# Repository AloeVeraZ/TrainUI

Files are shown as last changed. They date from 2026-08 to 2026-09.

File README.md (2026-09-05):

<div align="center">

# Train UI

### A live NYC train display I built in two sizes




</div>

---

## Overview

I built Train UI so I could see the next trains without opening an app. Pick a train and station once, then leave the display running.

## How it works

Both versions connect directly to the MTA's public realtime feeds. Your train and station stay saved on the device, which refreshes arrivals, service status, weather, time, and connection information without a phone app, account, or API key.

## Choose a version

| Train UI XL | Train UI Mini |
| --- | --- |
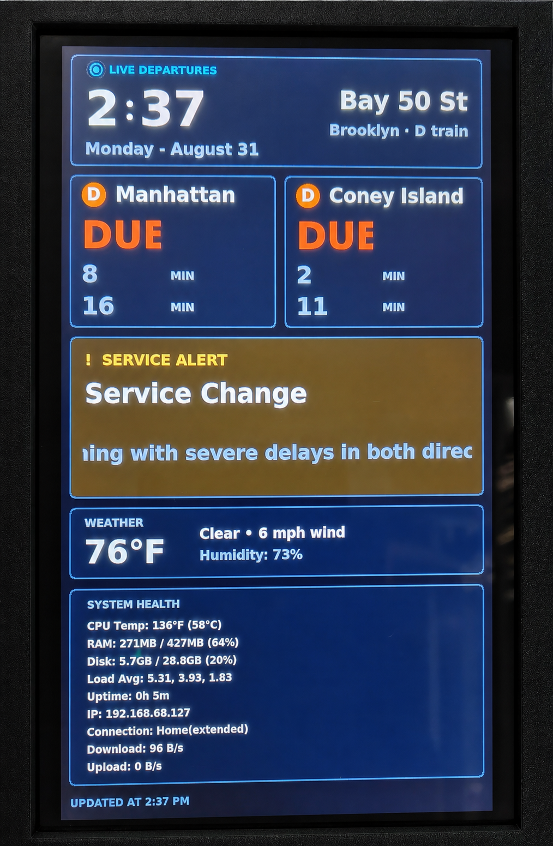
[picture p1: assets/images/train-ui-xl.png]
Train UI XL showing live departures
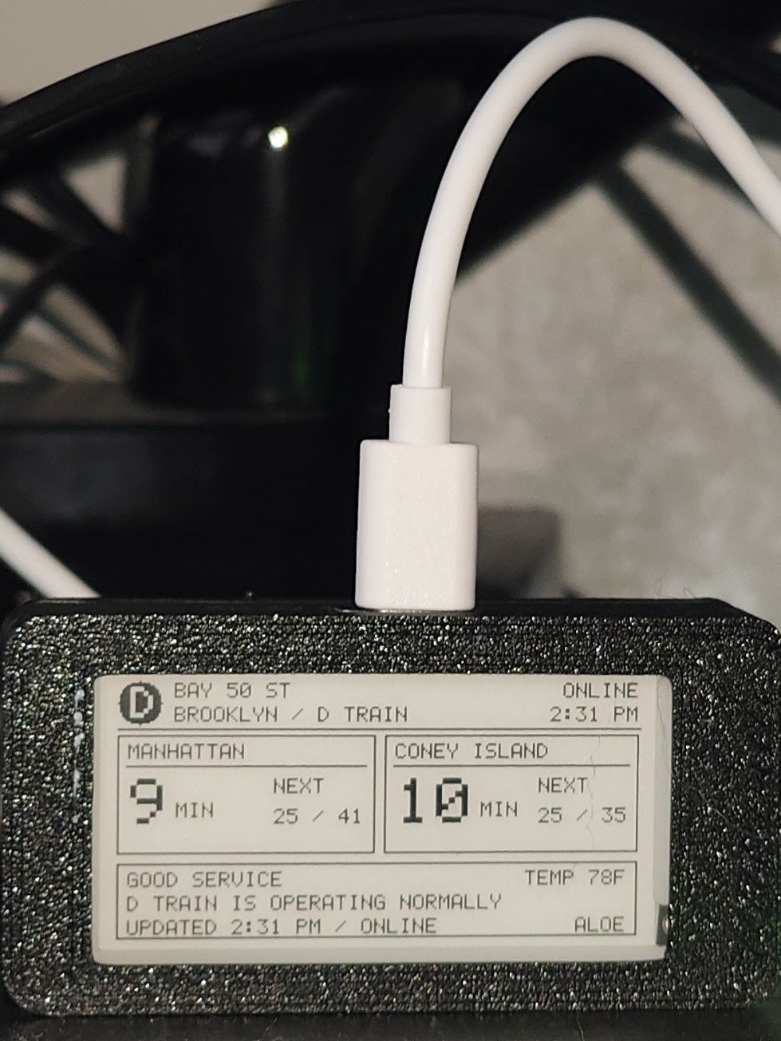
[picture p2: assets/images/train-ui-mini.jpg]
Train UI Mini e-paper display
|  |  |
| Raspberry Pi Zero W and a 10.1-inch color screen | ESP32-S3 and a 2.13-inch e-paper screen |
| Full dashboard, weather, and Pi health | Smaller, cheaper, and simpler |
| [Build the XL](Train%20UI%20XL/) | [Build the Mini](Train%20UI%20Mini/) |

## XL CAD files

| File | Use |
| --- | --- |
| [case for screen.step](Train%20UI%20XL/CAD/case%20for%20screen.step) | Full STEP assembly for reference and editing |
| [Only 3DP files.step](Train%20UI%20XL/CAD/Only%203DP%20files.step) | **Only the parts that need to be 3D printed** |
| [case for screen.f3z](Train%20UI%20XL/CAD/case%20for%20screen.f3z) | Editable Fusion 360 archive |

Use **Only 3DP files.step** when you only want the printable enclosure pieces. It leaves out the reference electronics and hardware from the full assembly.

## What they show

- Arrivals in both directions
- MTA service status and alerts
- Weather, time, and connection status
- Live public data with no API key

For a bar or other across-the-room installation, use the separate
[Train UI XL Trackside edition](Train%20UI%20XL/Train%20UI%20XL%20Trackside/).

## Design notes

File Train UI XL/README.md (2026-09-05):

<div align="center">

# Train UI XL

### My full-size NYC train display





<a href="#overview">Train UI XL showing live departures</a>

[Parts](#parts) • [CAD](#cad-files) • [Assembly](Assembly%20Guide/) • [Install](#install) • [Commands](#commands)

</div>

---

## Overview

I built Train UI XL around a Raspberry Pi Zero W and a 10.1-inch screen. It shows arrivals, service alerts, weather, time, and Pi health, then starts itself whenever the Pi boots.

### Trackside edition

[Train UI XL Trackside](Train%20UI%20XL%20Trackside/) is the separate bar-commissioned
layout. It keeps the same hardware and installer, but uses an extra-large clock,
large departure times, a five-day forecast, and a compact system-health footer.

> [!WARNING]
> This build needs soldering. Keep power disconnected. Feed the cut Micro-USB cable through the printed back **before soldering**, verify polarity with a multimeter, solder red to `V` and black to `G`, insulate every unused wire, and check for a `V`–`G` short before power-up.

## Parts

This is the bill of materials for the XL build.

| Qty. | Core part |
| ---: | --- |
| 1 | Original Raspberry Pi Zero W |
| 1 | 10.1-inch 1024 × 600 HDMI display |
| 1 | MicroSD card |
| 1 | Stable 5V power supply |

### Cables and hardware

<table>
  <tr>
    <td width="33%" valign="top" align="center">
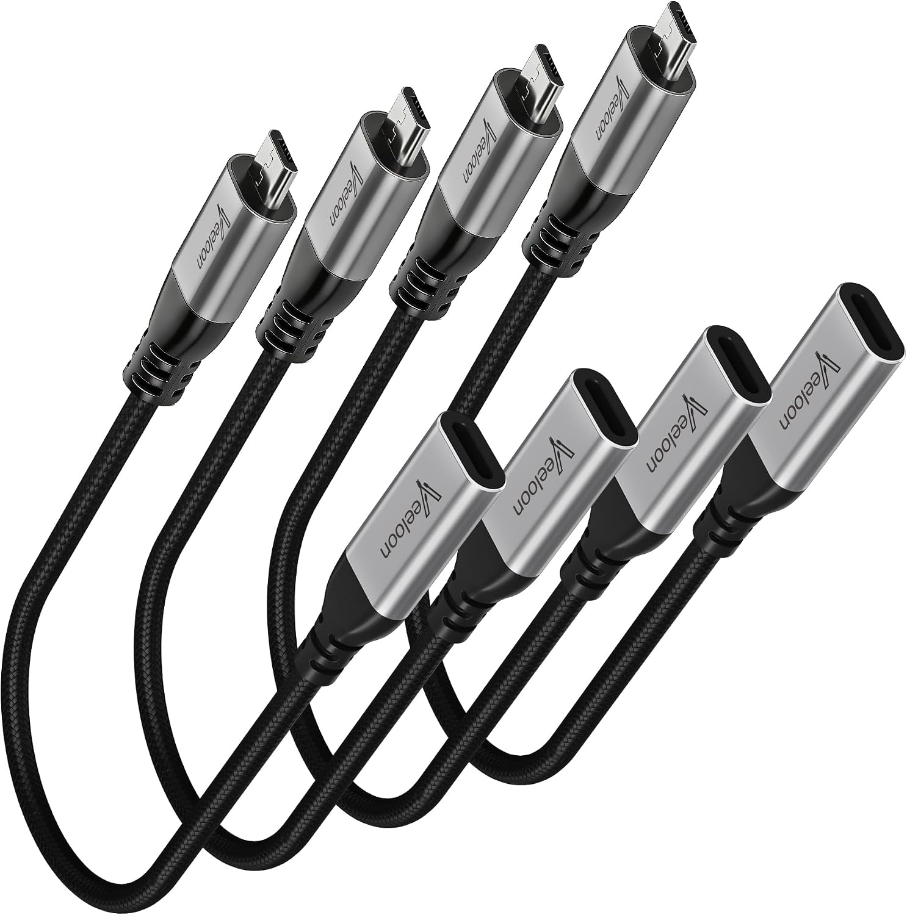
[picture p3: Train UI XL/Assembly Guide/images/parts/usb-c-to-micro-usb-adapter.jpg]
USB-C female to Micro-USB male adapter cable
      <br>
      <strong><a href="https://www.amazon.com/dp/B0G5YZJLVZ">USB-C to Micro-USB adapter lead</a></strong><br>
      Becomes the internal Pi power lead.
    </td>
    <td width="33%" valign="top" align="center">
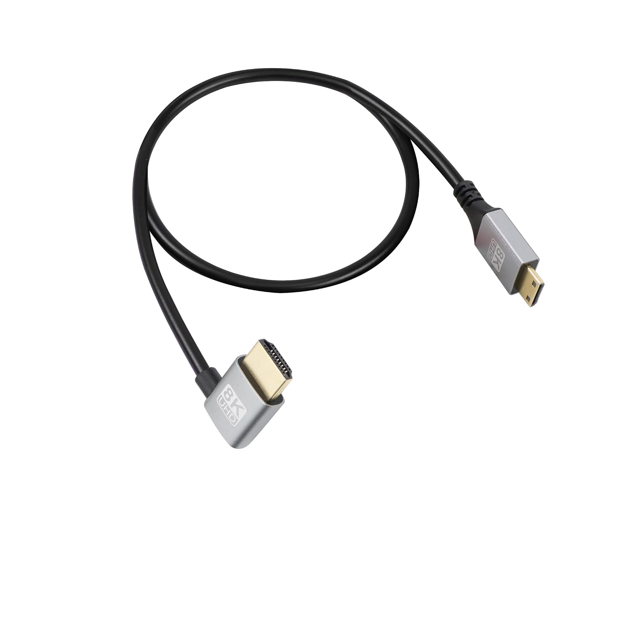
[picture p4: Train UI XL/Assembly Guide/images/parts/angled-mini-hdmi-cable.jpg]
Angled HDMI to mini-HDMI cable
      <br>
      <strong><a href="https://www.amazon.com/dp/B0CNGV7FQJ">90-degree HDMI to mini-HDMI cable</a></strong><br>
      Connects the Pi to the screen.
    </td>
    <td width="33%" valign="top" align="center">
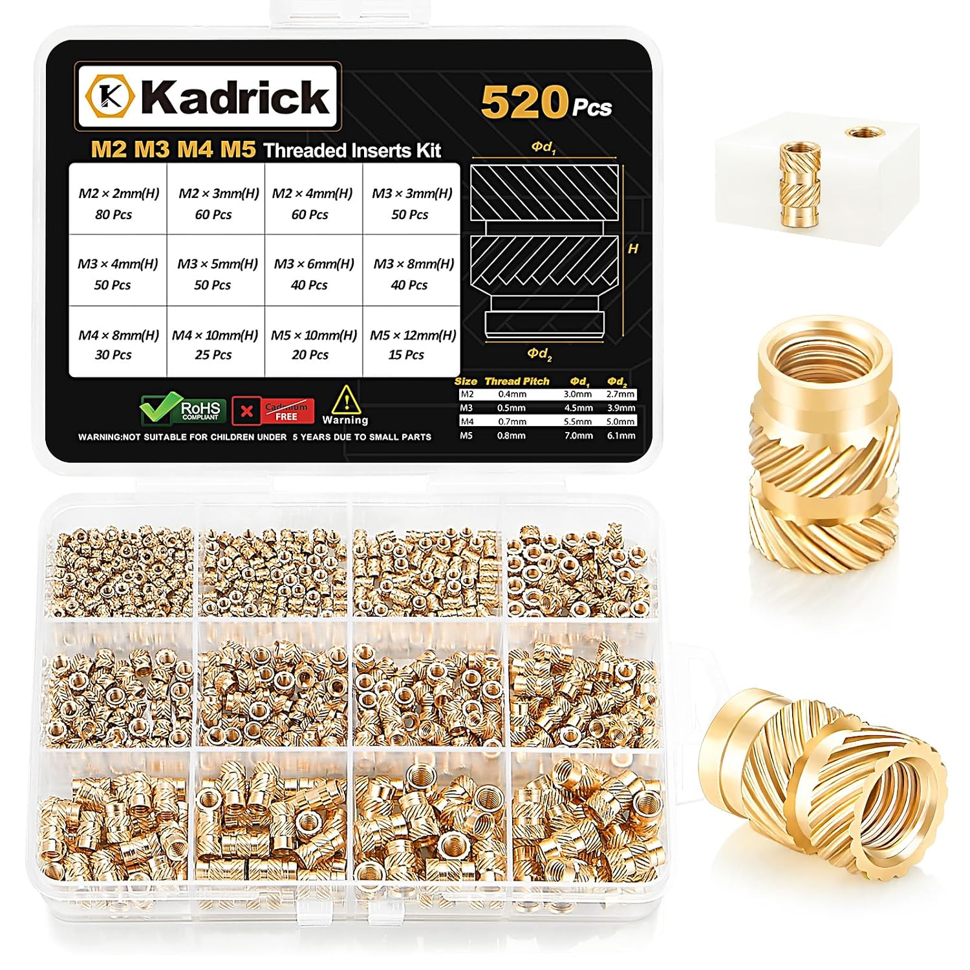
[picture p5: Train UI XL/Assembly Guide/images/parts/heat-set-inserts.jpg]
M2 through M5 heat-set insert kit
      <br>
      <strong><a href="https://www.amazon.com/dp/B0D5V3TZLB">M2–M5 heat-set inserts</a></strong><br>
      Adds metal threads to the printed parts.
    </td>
  </tr>
  <tr>
    <td width="33%" valign="top" align="center">
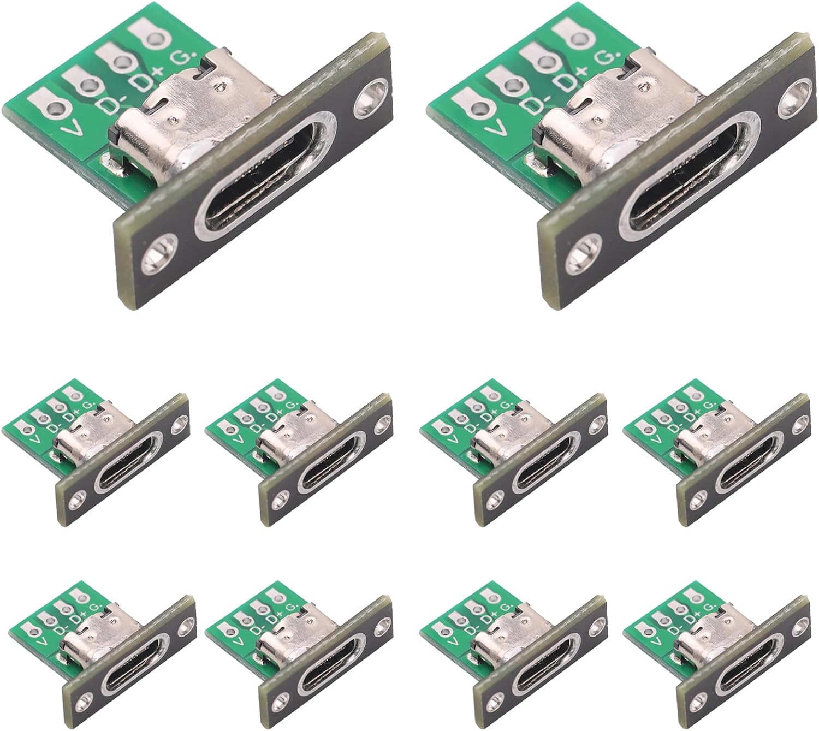
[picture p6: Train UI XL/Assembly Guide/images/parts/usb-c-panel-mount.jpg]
USB-C female panel-mount socket boards
      <br>
      <strong><a href="https://www.amazon.com/dp/B0F3WVBGCP">USB-C panel-mount socket</a></strong><br>
      Becomes the outside power inlet.
    </td>
    <td width="33%" valign="top" align="center">
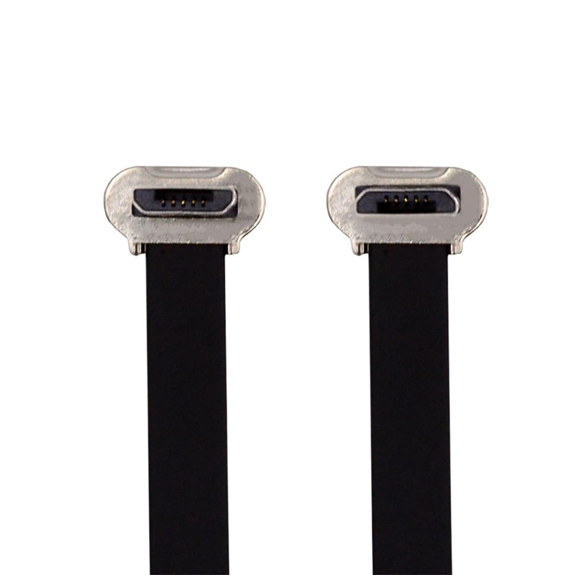
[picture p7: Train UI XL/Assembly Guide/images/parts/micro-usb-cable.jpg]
Short 90-degree Micro-USB male-to-male cable
      <br>
      <strong><a href="https://www.amazon.com/dp/B0F87W7P59">Short 90-degree Micro-USB cable</a></strong><br>
      Keeps the internal power run compact.
    </td>
    <td width="33%" valign="top" align="center">
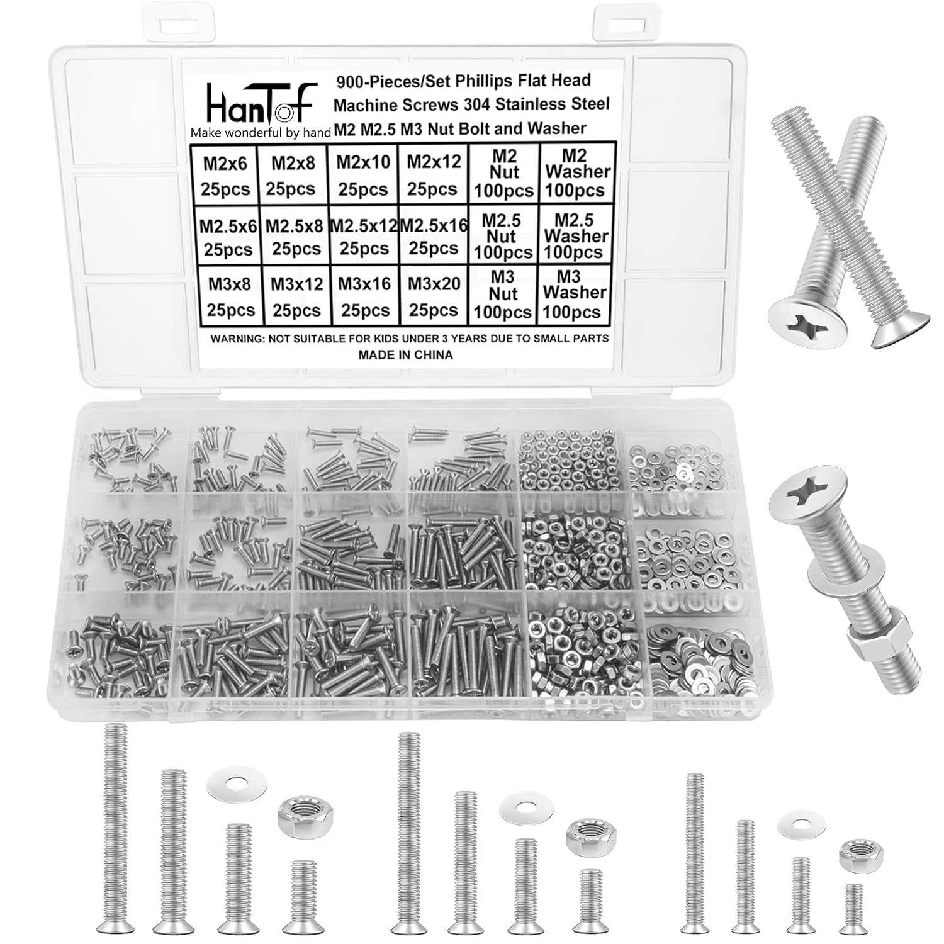
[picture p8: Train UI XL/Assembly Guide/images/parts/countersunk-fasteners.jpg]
Countersunk M2, M2.5, and M3 fastener assortment
      <br>
      <strong><a href="https://www.amazon.com/dp/B0FF4TDYKZ">Countersunk fasteners</a></strong><br>
      Holds low-profile parts flush.
    </td>
  </tr>
  <tr>
    <td colspan="3" align="center">
      <table width="67%">
        <tr>
          <td width="50%" valign="top" align="center">
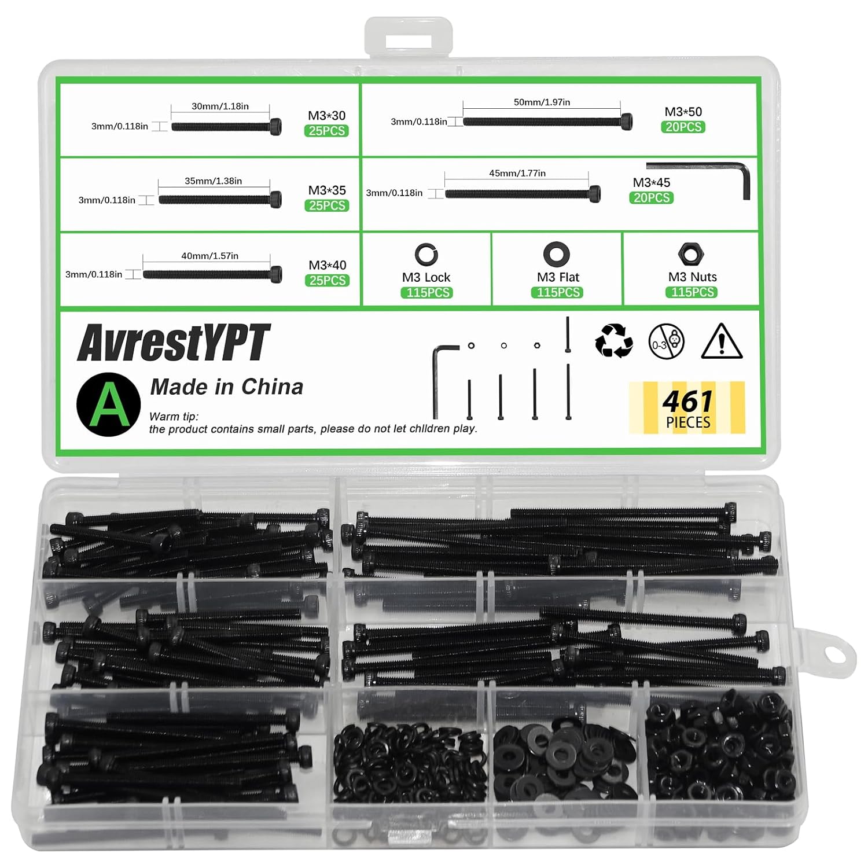
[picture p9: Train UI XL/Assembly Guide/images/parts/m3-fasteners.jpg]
M3 socket-head screw, nut, and washer assortment
            <br>
            <strong><a href="https://www.amazon.com/dp/B0FGJ9FRGQ">M3 socket-head fasteners</a></strong><br>
            Use four M3 × 25 mm screws to close the case.
          </td>
          <td width="50%" valign="top" align="center">
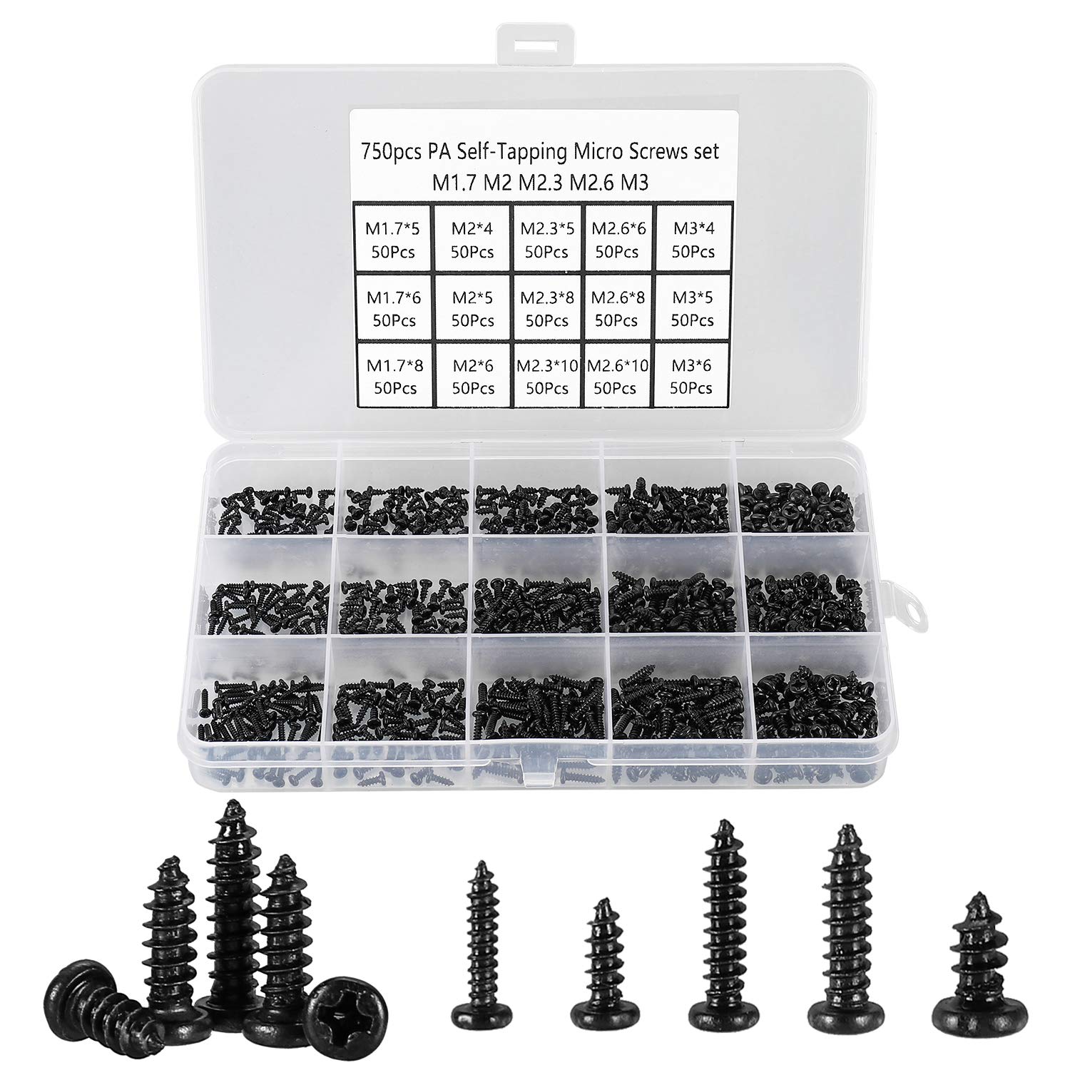
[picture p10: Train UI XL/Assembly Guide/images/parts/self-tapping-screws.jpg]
Small black self-tapping screw assortment
            <br>
            <strong><a href="https://www.amazon.com/dp/B07ZH9GJWP">Small self-tapping screws</a></strong><br>
            Secures light internal parts.
          </td>
        </tr>
      </table>
    </td>
  </tr>
</table>

**Tools:** soldering iron, wire cutters, wire strippers, multimeter, heat-shrink, heat-set tip, and matching hand tools.

## CAD files

| File | Use |
| --- | --- |
| [case for screen.step](CAD/case%20for%20screen.step) | Complete STEP assembly |
| [Only 3DP files.step](CAD/Only%203DP%20files.step) | **3D-printed parts only** |
| [case for screen.f3z](CAD/case%20for%20screen.f3z) | Editable Fusion 360 archive |

If you only want to slice or print the enclosure, download **Only 3DP files.step**. The full STEP and Fusion archive also include reference assembly content.

## Assembly

The [step-by-step assembly guide](Assembly%20Guide/) covers the faceplate, screen, Pi, power inlet, wiring, and final enclosure.

## Install

1. Use [Raspberry Pi Imager](https://www.raspberrypi.com/software/) to install Raspberry Pi OS 32-bit with Desktop.
2. Add 2.4 GHz Wi-Fi, enable SSH, and create your user.
3. Connect the screen, SSH into the Pi, and run:

```bash
curl -fsSL https://raw.githubusercontent.com/AloeVeraZ/TrainUI/main/Train%20UI%20XL/installer/install.sh | bash
```

Choose a train and station, then answer `Y` or `N` for daily display sleep. Enter exactly four digits in 24-hour `HHMM` format: `2300` is 11:00 PM, `0800` is 8:00 AM, and `2400` is midnight. The installer then sets automatic startup and Wi-Fi recovery and reboots.

If the Pi stays offline for 30 seconds, join **TrainUI** with password **TRAINUI1** and open `http://10.42.0.1`. The screen shows these setup details only while the hotspot is active.

## Update, change stations, or change sleep time

Run the same command again. Normal reruns use the fast update path: they download only the small XL runtime files, skip unchanged system setup, and do not reboot. You can change both the train/station and daily sleep times during the update:

```bash
curl -fsSL https://raw.githubusercontent.com/AloeVeraZ/TrainUI/main/Train%20UI%20XL/installer/install.sh | bash
```

## Commands

```bash
# Update TrainUI, change the station, and review the sleep schedule
curl -fsSL https://raw.githubusercontent.com/AloeVeraZ/TrainUI/main/Train%20UI%20XL/installer/install.sh | bash

# Change only the daily display sleep schedule
trainui-schedule

# View the log
tail -f "$HOME/TrainUI/Train UI XL/trainui.log"

# Check Wi-Fi setup
systemctl status trainui-wifi-setup.service
sudo journalctl -u trainui-wifi-setup.service --since today

```

Scheduled sleep powers down only the display. The desktop stays logged in and TrainUI keeps running, so wake time returns directly to the dashboard instead of a login screen.

## Quick fixes

| Problem | Check |
| --- | --- |
| SSH fails | Try the Pi's IP address and confirm SSH is enabled. |
| Screen stays blank | Let Raspberry Pi OS reach the desktop, then check the log. |
| Wi-Fi fails | Use 2.4 GHz, or join the setup hotspot after 30 seconds. |
| Rotation is wrong | Mount the screen at 270 degrees and rerun the installer. |

## Development

```bash
python3 -m unittest discover -s tests -v
python3 tests/validate_live_feeds.py
python3 timertest.py --smoke-test
```

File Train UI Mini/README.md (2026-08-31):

<div align="center">

# Train UI Mini

### My small e-paper NYC train display





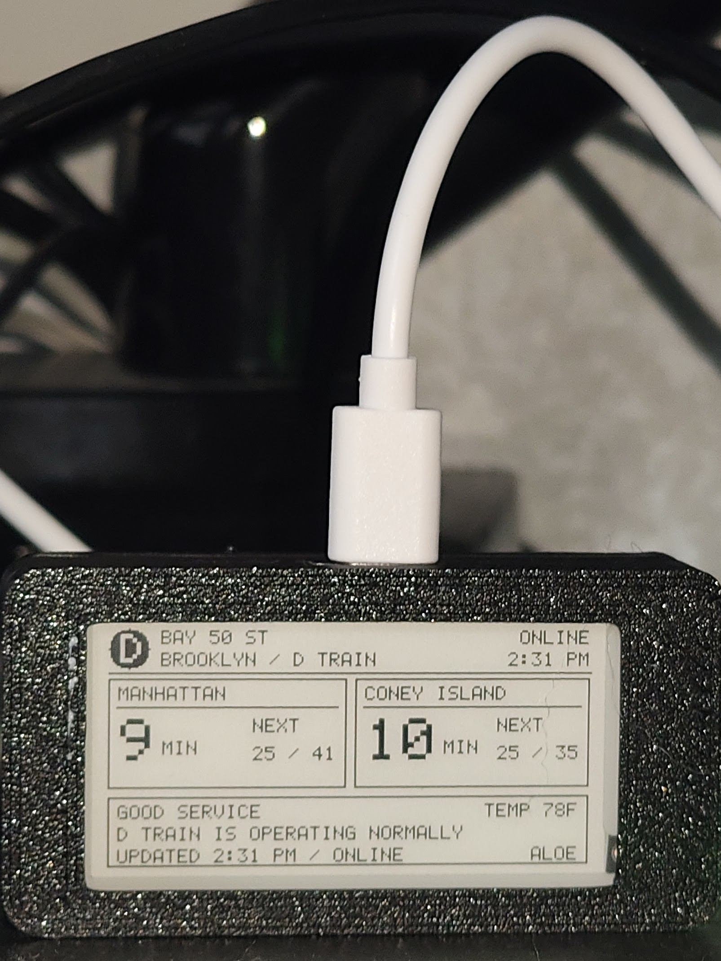
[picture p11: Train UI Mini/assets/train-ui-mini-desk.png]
Train UI Mini e-paper display


</div>

---

## Overview

I built Train UI Mini as a cheaper version of [Train UI XL](../Train%20UI%20XL/). It shows arrivals, service status, temperature, time, and connection status on one ESP32-S3 e-paper board.

## Parts

| Qty. | Part |
| --- | --- |
| 1 | [Elecrow CrowPanel ESP32-S3 2.13-inch e-paper display](https://www.amazon.com/dp/B0H25DMJ8M) |
| 1 | USB-C data cable |
| Optional | [3D-printed desk case](https://www.printables.com/model/1566902-case-for-crowpanel-213-epaper/related) |

## Setup

1. Install **esp32 by Espressif Systems** in Arduino IDE.
2. Open `TrainUIMiniCode/TrainUIMiniCode.ino`.
3. Use these settings and upload:

| Setting | Value |
| --- | --- |
| Board | ESP32S3 Dev Module |
| Flash Size | 8MB (64Mb) |
| PSRAM | OPI PSRAM |
| USB CDC On Boot | Enabled |

On first boot, join **TrainUIMini** with password **TRAINUI1**. Open `http://192.168.4.1`, enter your Wi-Fi, and choose a train and station.

## Controls

| Control | Action |
| --- | --- |
| Menu | Open setup again |
| Dial press | Switch between live and sample data |
| Back | Refresh |

The board uses public MTA and Open-Meteo data. No app, account, server, or API key is needed.

Train UI Mini is available under the [MIT License](LICENSE).

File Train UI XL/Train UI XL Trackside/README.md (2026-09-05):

# Train UI XL Trackside

Train UI XL Trackside is a dedicated, easy-to-read version commissioned for a
bar. It keeps the same Raspberry Pi Zero W hardware, MTA live departures,
Wi-Fi recovery, scheduled display power, automatic startup, and installation
flow as [Train UI XL](../README.md). It lives in its own folder so the
Trackside layout can be maintained separately from the main display.

## What is different

- The clock and date are enlarged for viewing across a room, with responsive
  sizing so the full weekday and month remain readable.
- Departure numbers and their `MIN` labels are enlarged to the largest size
  that fits each portrait card without clipping.
- The service-change panel is replaced by a five-day weather forecast.
- System health is compact and stays at the bottom with only CPU temperature,
  uptime, IP address, and Wi-Fi connection.

The Trackside installer uses separate application, configuration, log, Wi-Fi,
schedule, and systemd names so it does not overwrite a regular Train UI XL
installation. Its setup hotspot is **TrainUI Trackside** with password
**TRAINUI1** at `http://10.42.0.1`.

## Install

Use Raspberry Pi OS 32-bit with Desktop, enable SSH, add the 2.4 GHz network in
Raspberry Pi Imager, and run this as the normal Pi user:

```bash
curl -fsSL https://raw.githubusercontent.com/AloeVeraZ/TrainUI/main/Train%20UI%20XL/Train%20UI%20XL%20Trackside/installer/install.sh | bash
```

Choose the train and station, then answer `Y` or `N` for daily display sleep.
Enter times as exactly four digits in 24-hour `HHMM` format: `2300` is 11:00
PM, `0800` is 8:00 AM, and `2400` is midnight.

## Commands

```bash
# Update Trackside, change the station, or review the sleep schedule
curl -fsSL https://raw.githubusercontent.com/AloeVeraZ/TrainUI/main/Train%20UI%20XL/Train%20UI%20XL%20Trackside/installer/install.sh | bash

# Change only the Trackside display schedule
trainui-trackside-schedule

# View the Trackside log
tail -f "$HOME/TrainUI-Trackside/Train UI XL/Train UI XL Trackside/trainui-trackside.log"
```

Scheduled sleep powers down only the display. The logged-in desktop and
Trackside app remain active, so wake time returns directly to the dashboard.

## Hardware and assembly

Use the shared [parts and CAD files](../README.md) and the
[step-by-step assembly guide](../Assembly%20Guide/). The enclosure, screen,
Raspberry Pi Zero W orientation, power wiring, and fasteners are unchanged.

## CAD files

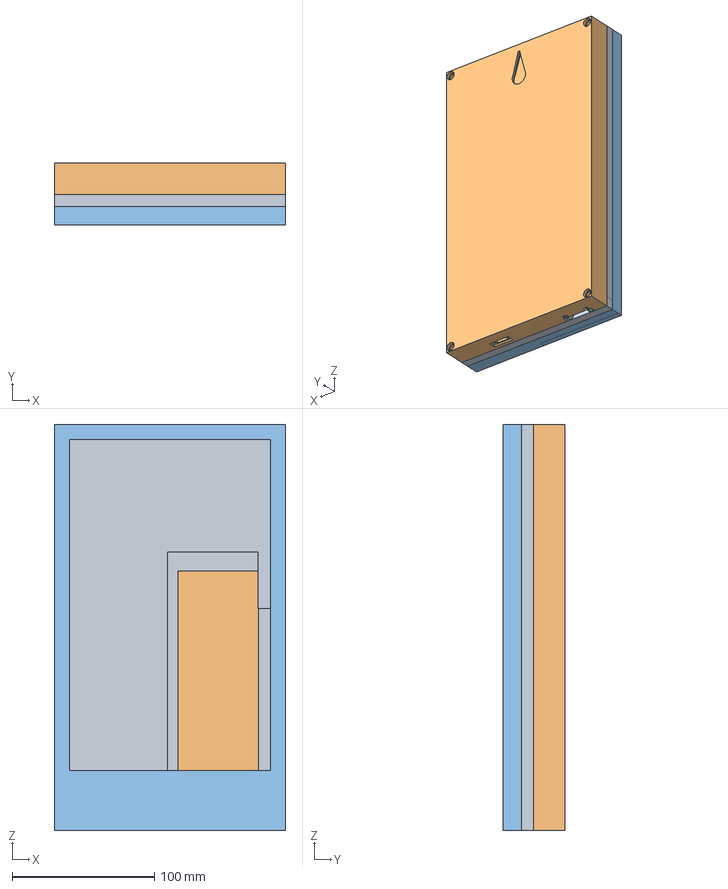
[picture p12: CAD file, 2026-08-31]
Train UI XL/CAD/Only 3DP files.step
162.4 x 43.3 x 285.3 mm

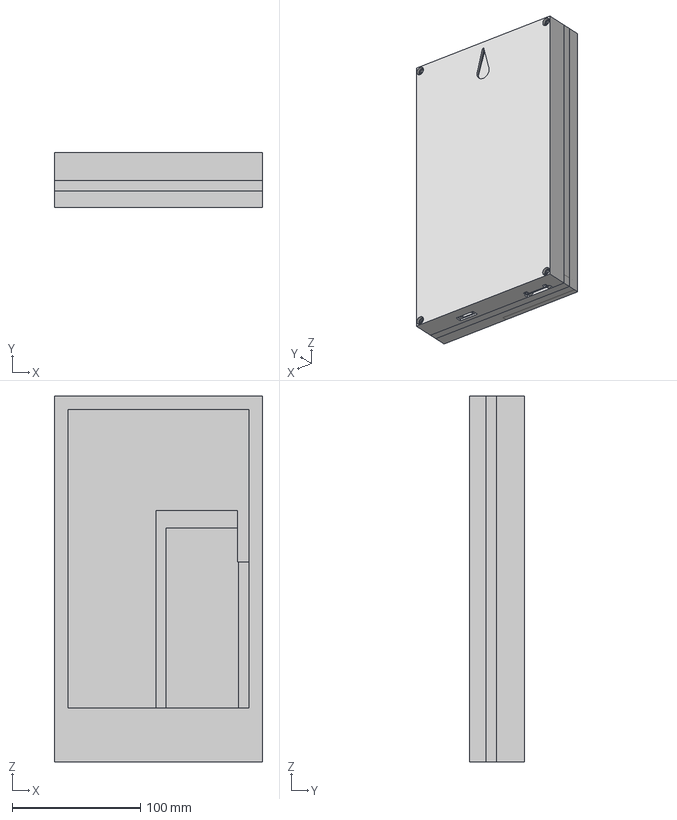
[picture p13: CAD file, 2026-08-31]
Train UI XL/CAD/case for screen.step
162.4 x 43.3 x 285.4 mm
Raspberry_pizero_PCB
Micro USB_input_female (short)-SMT x 2
0204 - Capacitor x 34
0204- Resistor x 17
CAP-0306 x 2
Raspberry_pizero_BCM2835 with VC4
Crystal 3.4x2.4mm
32,768 Khz Crystal
0805- Capacitor x 7
0204 - Capacitor Brown x 8
6-Pin SOT
micro sd molex
hdmi type C
Voltage Regulator 3x3mm 12-Pin
1210 inductor x 3

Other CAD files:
Train UI XL/CAD/case for screen.f3z

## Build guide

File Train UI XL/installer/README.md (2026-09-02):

<div align="center">

# Train UI XL Installer

### One command for setup and updates




</div>

---

## Before you start

- Use Raspberry Pi OS 32-bit with Desktop.
- Enable SSH and add 2.4 GHz Wi-Fi in Raspberry Pi Imager.
- Run this as your normal user, not with `sudo`.

## Run it

```bash
curl -fsSL https://raw.githubusercontent.com/AloeVeraZ/TrainUI/main/Train%20UI%20XL/installer/install.sh | bash
```

Choose a train and station, then answer `Y` or `N` for daily display sleep. Enter time as four digits in 24-hour `HHMM` format: `2300` is 11:00 PM, `0800` is 8:00 AM, and `2400` is midnight. Run the same command again to update TrainUI or change the station and schedule. Normal reruns skip unchanged system setup and do not reboot; they download only the small XL runtime files, not the CAD models or documentation photos.

Your selection stays in `~/.config/trainui/config.json`. If an old checkout is damaged or changed, the installer saves it as `~/TrainUI.backup.*` before replacing it.

## Wi-Fi setup

Raspberry Pi Imager Wi-Fi stays preferred. After 30 seconds without Wi-Fi or Ethernet, join **TrainUI** with password **TRAINUI1**, then open `http://10.42.0.1`.

## Quick checks

```bash
tail -n 100 "$HOME/TrainUI/Train UI XL/trainui.log"
systemctl status trainui-wifi-setup.service
sudo journalctl -u trainui-wifi-setup.service --since today
```

Change or disable the daily schedule later with one command:

```bash
trainui-schedule
```

During scheduled sleep, only the display powers down. TrainUI and the logged-in desktop stay running, so the display wakes straight back into TrainUI without a login screen.

If the setup menu cannot use the terminal, reconnect with SSH and run the command directly. Hardware and assembly instructions are in the [Train UI XL README](../README.md).

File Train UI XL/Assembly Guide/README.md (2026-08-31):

<div align="center">

# Train UI XL Assembly Guide

### Build the enclosure in four steps

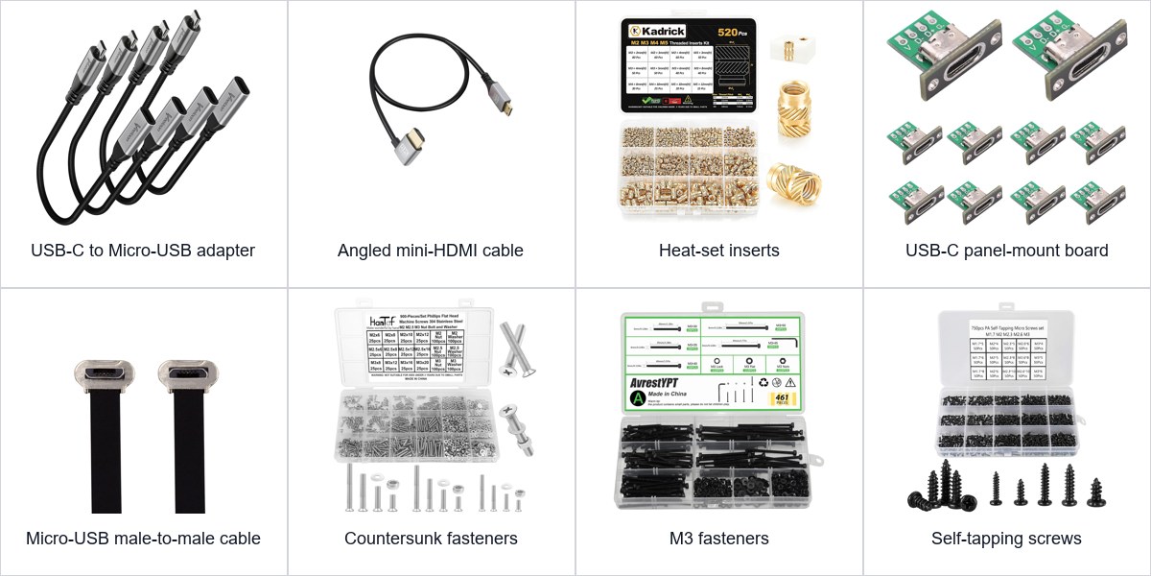
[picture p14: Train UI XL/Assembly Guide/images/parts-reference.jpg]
Train UI XL parts reference


[Parts](../README.md#parts) • [Faceplate](#step-1--prepare-the-front-faceplate-and-install-the-screen) • [Pi](#step-2--prepare-the-middle-plate-and-mount-the-raspberry-pi-zero-w) • [Power](#step-3--build-and-install-the-usb-c-power-inlet) • [Close](#step-4--square-and-close-the-enclosure)

</div>

---

I designed the case as a front faceplate, middle plate, and back plate. Check the [bill of materials](../README.md#parts) before starting.

> [!WARNING]
> Keep power disconnected while cutting, stripping, soldering, or checking wiring. Keep heat away from the screen, cables, and circuit boards.

## Step 1 — Prepare the front faceplate and install the screen

**Parts:** front faceplate, 4 M3 × 4 mm heat-set threaded inserts, heat-set tip, and 10.1-inch display.

### 1. Install the inserts

The empty corner holes look like this:

<p align="center">
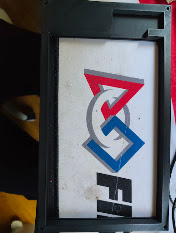
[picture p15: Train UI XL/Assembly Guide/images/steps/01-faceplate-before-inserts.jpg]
Train UI XL front faceplate before installing the heat-set inserts
  
</p>

Heat one insert at a time. Press it straight in until flush, remove the tip without twisting, and let it cool. Repeat at all four corners.

<p align="center">
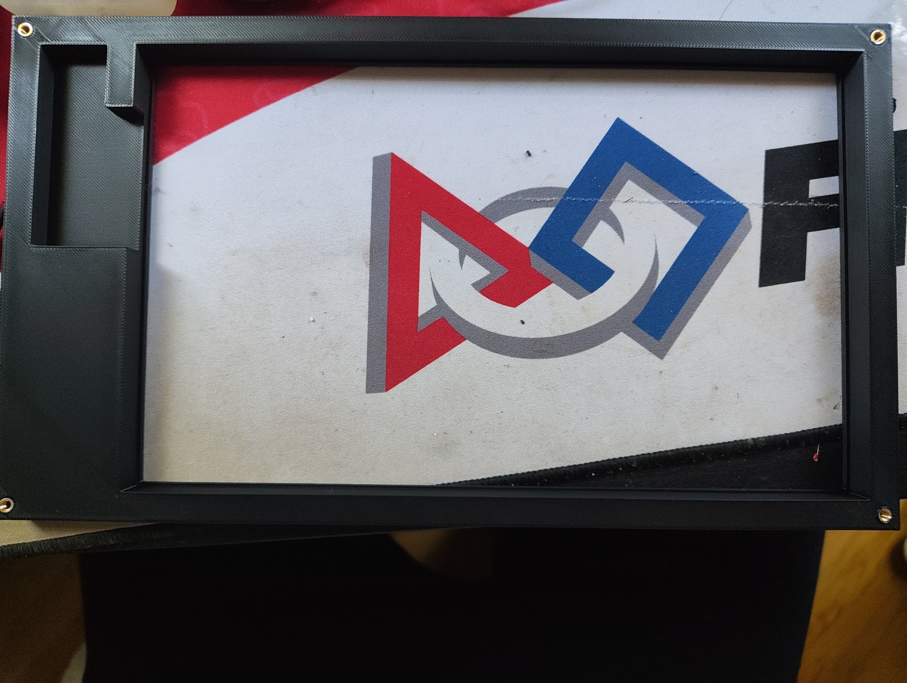
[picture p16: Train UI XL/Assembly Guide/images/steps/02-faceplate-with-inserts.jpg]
Train UI XL front faceplate with four M3 by 4 millimeter heat-set inserts installed
  
</p>

### 2. Seat the screen

Place the faceplate front-down on a soft surface. Lower the screen in from the rear with its viewing side toward the front. Keep pressure off the LCD, controller, and ribbon cable. The screen should sit flat inside the recessed edge.

<p align="center">
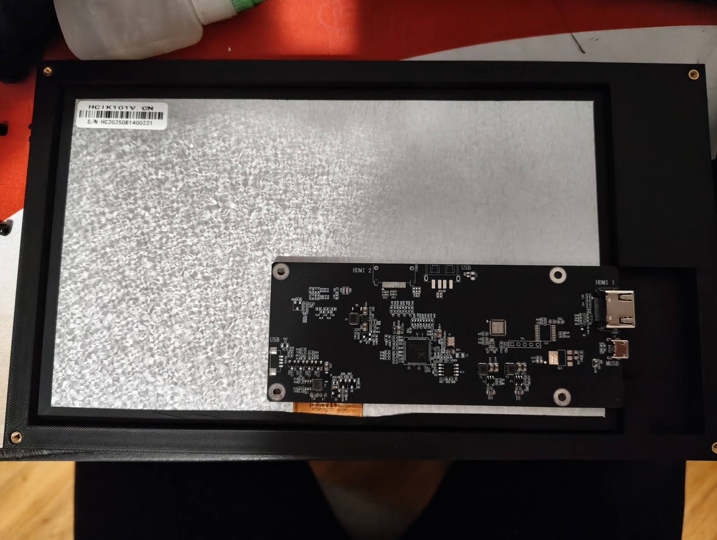
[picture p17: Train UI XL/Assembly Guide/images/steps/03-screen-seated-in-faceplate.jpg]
Rear view of the Train UI XL display seated in the front faceplate
  
</p>

## Step 2 — Prepare the middle plate and mount the Raspberry Pi Zero W

**Parts:** middle plate, 4 M2 × 4 mm heat-set threaded inserts, heat-set tip, Pi Zero W, and 4 M2 × 6 mm screws.

### 1. Install the Pi inserts

Orient the plate with the large opening at the upper left. Use the four small holes grouped at the bottom left—not the larger enclosure holes.

<p align="center">
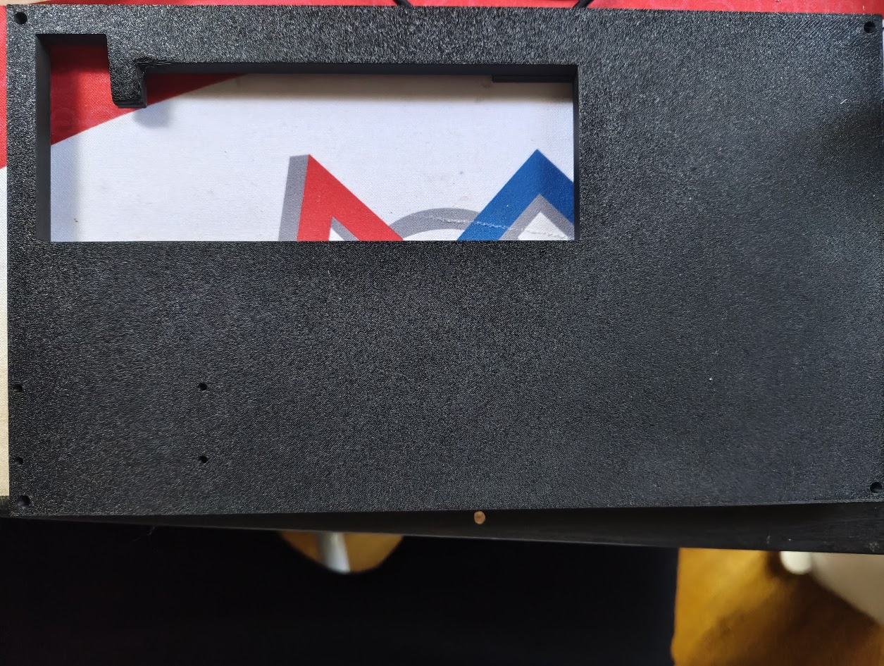
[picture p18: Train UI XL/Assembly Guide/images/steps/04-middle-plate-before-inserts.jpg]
Train UI XL middle plate before installing the Raspberry Pi mounting inserts
  
</p>

Press each insert straight in until flush and let it cool.

<p align="center">
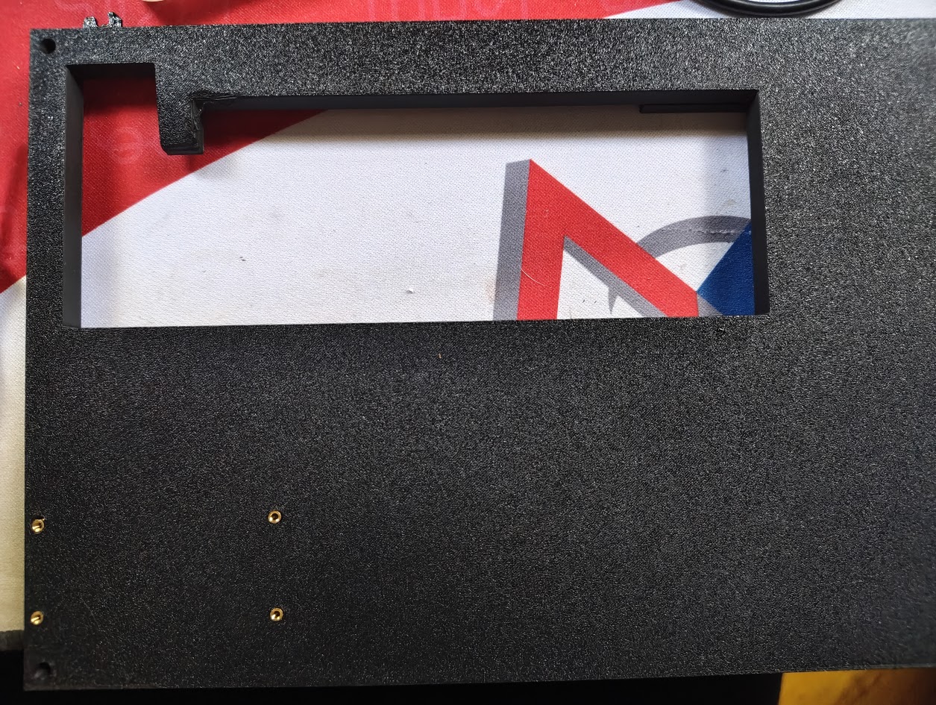
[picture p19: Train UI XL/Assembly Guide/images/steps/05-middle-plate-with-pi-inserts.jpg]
Train UI XL middle plate with four M2 by 4 millimeter Raspberry Pi mounting inserts installed
  
</p>

### 2. Mount the Pi

Start all four M2 × 6 mm screws, then tighten only until secure.

> [!IMPORTANT]
> Match the photo exactly or the back plate will not fit correctly. With the display controller at the bottom, the Pi sits at the upper right. Its green underside faces out and its connector edge points down.

Route the HDMI and power cables below the back-plate edge.

<p align="center">
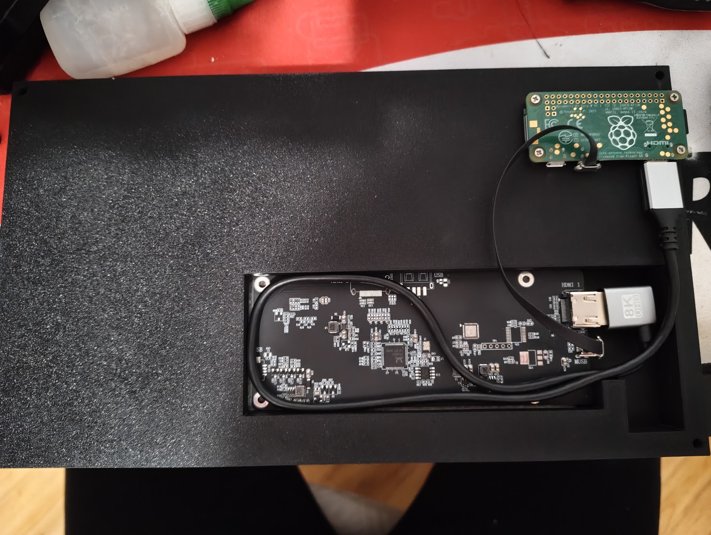
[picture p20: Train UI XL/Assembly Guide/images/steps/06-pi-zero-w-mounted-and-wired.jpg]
Correct Raspberry Pi Zero W orientation and cable routing on the Train UI XL middle plate
  
</p>

## Step 3 — Build and install the USB-C power inlet

**Parts:** back plate, USB-C panel-mount board, sacrificial Micro-USB lead, cutters, strippers, soldering iron, multimeter, insulation, and mounting screws.

### 1. Feed the cable

Cut off the unwanted end and keep the Micro-USB male plug. Strip the cut end. Insulate any unused wires.

Feed the cut end through the small back-plate opening **before soldering**. Keep the Micro-USB plug inside and the loose USB-C board outside. The molded plug cannot pass through this hole.

<p align="center">
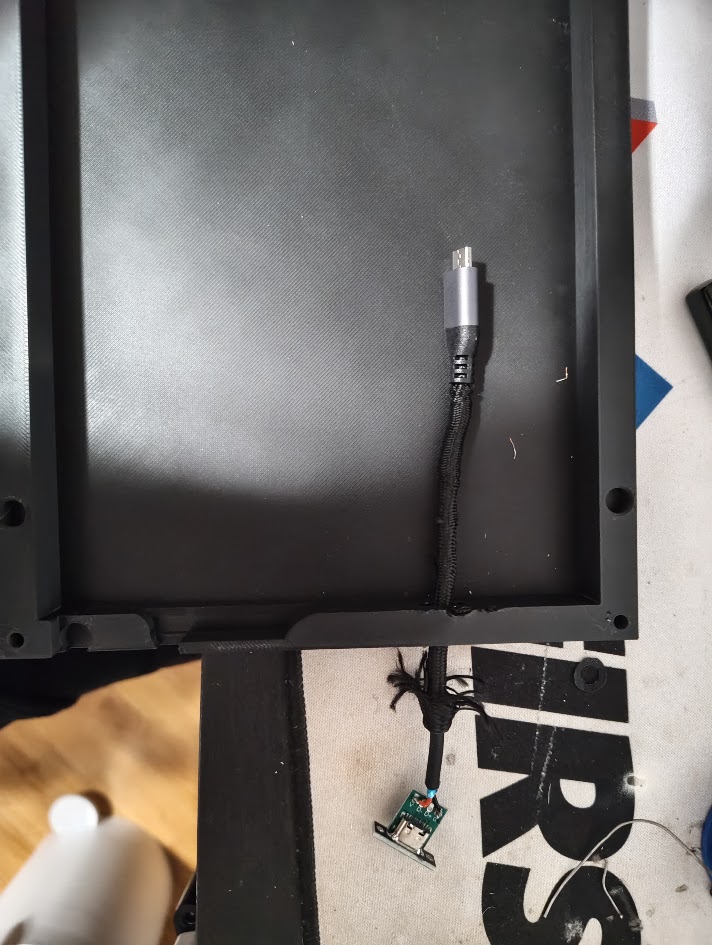
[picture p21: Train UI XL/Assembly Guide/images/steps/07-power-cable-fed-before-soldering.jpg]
Micro-USB power cable fed through the Train UI XL back plate before soldering
  
</p>

### 2. Solder and mount the inlet

- Solder the **red wire to `V`**.
- Solder the **black wire to `G`**.
- Leave `D+` and `D-` empty.

Verify the wires with a multimeter, insulate the joints, and confirm `V` is not shorted to `G`. Then bolt the USB-C board into the back plate with the socket facing outside.

<p align="center">
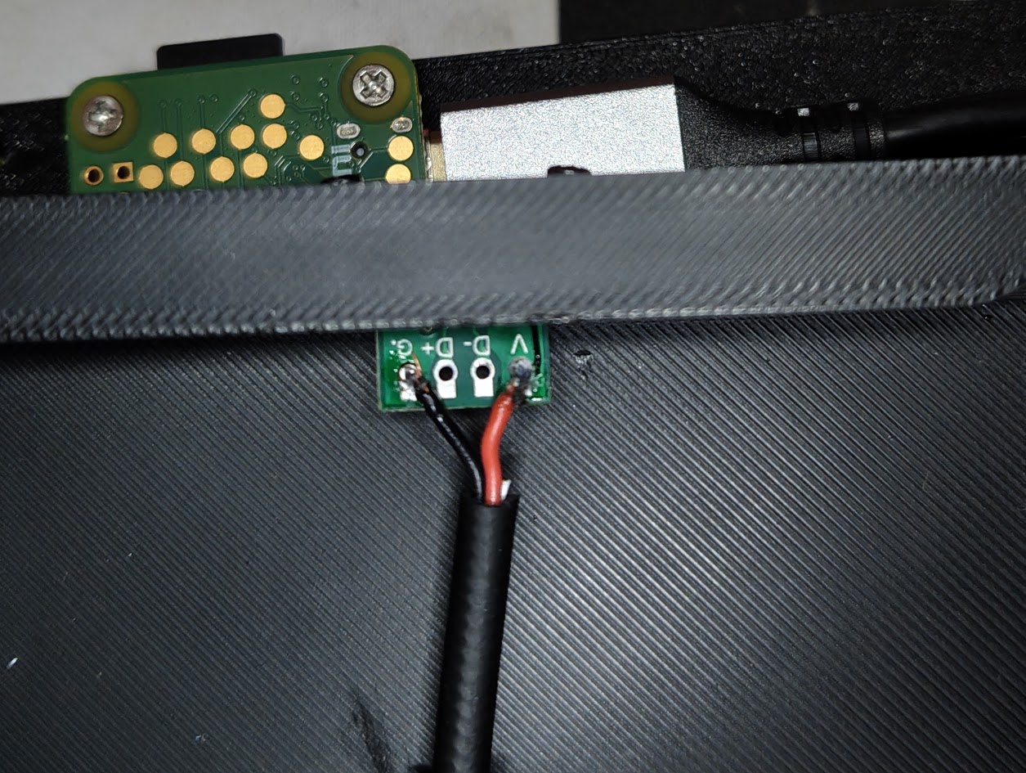
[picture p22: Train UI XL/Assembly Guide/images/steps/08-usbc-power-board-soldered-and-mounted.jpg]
Red wire soldered to V and black wire soldered to G on the mounted USB-C power board
  
</p>

### 3. Connect Pi power

> [!IMPORTANT]
> Plug the Micro-USB end into **`PWR IN`**, not the `USB`/OTG port. This cable carries power only.

Keep the cable loop low and away from the case edges and screw holes.

<p align="center">
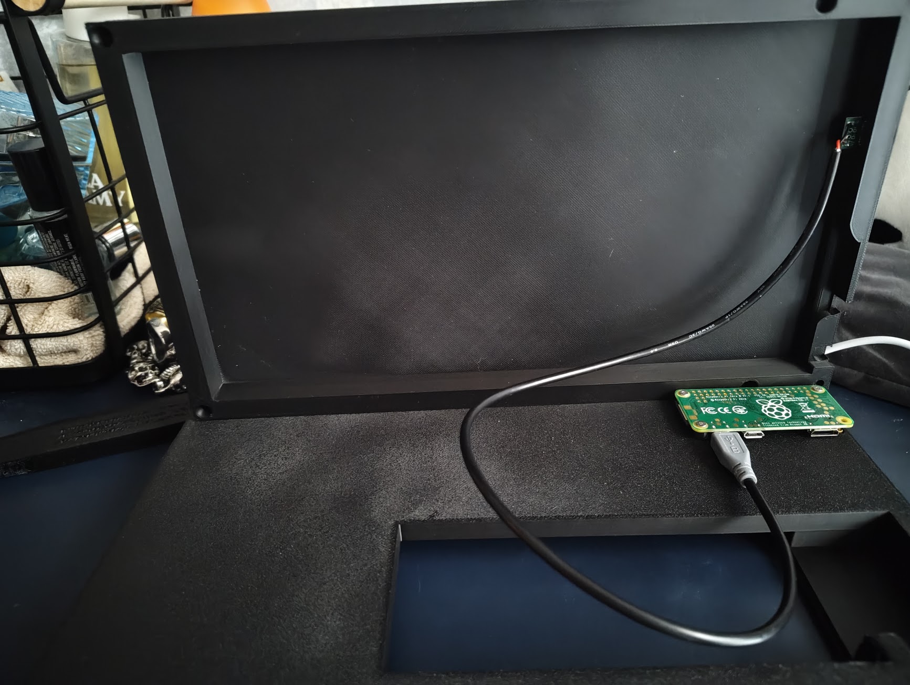
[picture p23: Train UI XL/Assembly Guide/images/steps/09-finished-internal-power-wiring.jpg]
Finished Train UI XL internal power wiring from the USB-C inlet to the Raspberry Pi Zero W power port
  
</p>

## Step 4 — Square and close the enclosure

**Parts:** the three finished layers, 4 M3 × 25 mm screws, matching tool, and a flat table.

### 1. Check the cables

Keep the build unplugged. Clear the perimeter and all four screw paths; no cable may cross an edge. If the plates do not close with light hand pressure, reopen them and move the obstruction. Never use the screws to force the case shut.

### 2. Square the case

Stand the case on one side on a flat table, with its faces approximately 90 degrees to the tabletop. Press the layers together until the edges and holes align. Keep pressure off the display.

Start all four M3 × 25 mm screws a few turns. Tighten them gradually across opposite corners until the seams close. Do not overtighten the inserts.

<p align="center">
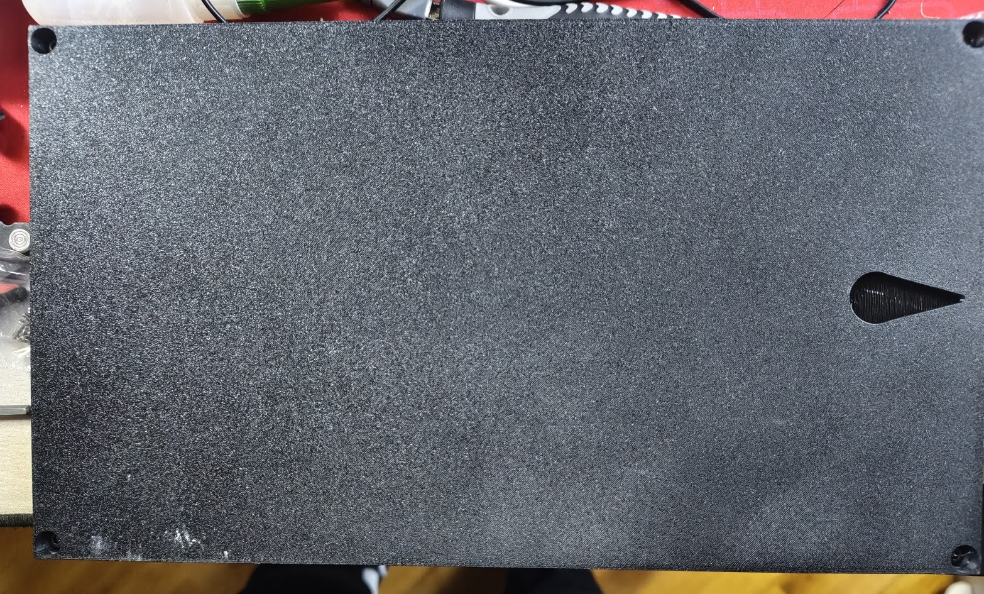
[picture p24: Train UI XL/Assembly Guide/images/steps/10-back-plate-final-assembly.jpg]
Finished rear view of the squared and bolted Train UI XL enclosure
  
</p>

### 3. Hang the finished display

The teardrop-shaped opening in the back plate is a keyhole slot for wall mounting. It is designed around a standard Phillips-head drywall screw with a head about 8 mm wide.

Fasten the screw into a wall stud or a suitable drywall anchor, leaving the head slightly proud of the wall. Pass the wide part of the keyhole over the screw head, then slide the display down into the narrow slot. Confirm the screw and anchor can support the complete display before letting go.

Check every seam once more. If no cable is trapped, the USB-C inlet is clear, and the wall mount is secure, the build is finished.

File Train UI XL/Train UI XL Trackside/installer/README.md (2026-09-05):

<div align="center">

# Train UI XL Trackside Installer

### One command for setup and updates




</div>

---

## Before you start

- Use Raspberry Pi OS 32-bit with Desktop.
- Enable SSH and add 2.4 GHz Wi-Fi in Raspberry Pi Imager.
- Run this as your normal user, not with `sudo`.

## Run it

```bash
curl -fsSL https://raw.githubusercontent.com/AloeVeraZ/TrainUI/main/Train%20UI%20XL/Train%20UI%20XL%20Trackside/installer/install.sh | bash
```

Choose a train and station, then answer `Y` or `N` for daily display sleep. Enter time as four digits in 24-hour `HHMM` format: `2300` is 11:00 PM, `0800` is 8:00 AM, and `2400` is midnight. Run the same command again to update TrainUI or change the station and schedule. Normal reruns skip unchanged system setup and do not reboot; they download only the small XL runtime files, not the CAD models or documentation photos.

Your selection stays in `~/.config/trainui-trackside/config.json`. If an old checkout is damaged or changed, the installer saves it as `~/TrainUI-Trackside.backup.*` before replacing it.

## Wi-Fi setup

Raspberry Pi Imager Wi-Fi stays preferred. After 30 seconds without Wi-Fi or Ethernet, join **TrainUI Trackside** with password **TRAINUI1**, then open `http://10.42.0.1`.

## Quick checks

```bash
tail -n 100 "$HOME/TrainUI-Trackside/Train UI XL/Train UI XL Trackside/trainui-trackside.log"
systemctl status trainui-trackside-wifi-setup.service
sudo journalctl -u trainui-trackside-wifi-setup.service --since today
```

Change or disable the daily schedule later with one command:

```bash
trainui-trackside-schedule
```

During scheduled sleep, only the display powers down. TrainUI and the logged-in desktop stay running, so the display wakes straight back into TrainUI without a login screen.

If the setup menu cannot use the terminal, reconnect with SSH and run the command directly. Hardware and assembly instructions are in the [Train UI XL README](../README.md).

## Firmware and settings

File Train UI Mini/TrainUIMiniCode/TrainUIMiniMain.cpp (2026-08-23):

#include <Arduino.h>
#include <Preferences.h>
#include <WebServer.h>
#include <WiFi.h>
#include <time.h>

#include "BoardPins.h"
#include "EpaperDisplay.h"
#include "MiniWeather.h"
#include "MtaClient.h"
#include "SubwayCatalog.h"
#include "UserConfig.h"

namespace {
constexpr uint32_t ARRIVAL_REFRESH_MS = 60UL * 1000UL;
constexpr uint32_t WEATHER_REFRESH_MS = 10UL * 60UL * 1000UL;
constexpr uint32_t ALERT_REFRESH_MS = 5UL * 60UL * 1000UL;
constexpr uint32_t PORTAL_TIMEOUT_MS = 15UL * 60UL * 1000UL;
constexpr char SETUP_SSID[] = "TrainUIMini";
constexpr char SETUP_PASSWORD[] = "TRAINUI1";

EpaperDisplay display;
Preferences preferences;
WebServer server(80);
MtaClient mta;
MiniWeather weatherClient;
ArrivalSnapshot arrivals;
MiniWeatherSnapshot weather;

String wifiSsid, wifiPassword, selectedRouteId, selectedStationId;
String serviceAlert, mtaError, weatherError;
const SubwayCatalog::RouteDef *selectedRoute = nullptr;
const SubwayCatalog::StationDef *selectedStation = nullptr;
bool configured = false;
bool offlineDemo = false;
bool portalRunning = false;
bool hasShownDashboard = false;
uint32_t portalStarted = 0;
uint32_t lastArrivalFetch = 0;
uint32_t lastWeatherFetch = 0;
uint32_t lastAlertFetch = 0;
uint16_t screenRefreshCount = 0;

class Button {
 public:
  explicit Button(uint8_t pin) : pin_(pin) {}
  void begin() { pinMode(pin_,INPUT_PULLUP); stable_=digitalRead(pin_); raw_=stable_; }
  bool pressed() {
    const bool reading=digitalRead(pin_);
    if (reading != raw_) { raw_=reading; changed_=millis(); }
    if (millis()-changed_>35 && reading != stable_) { stable_=reading; return stable_==LOW; }
    return false;
  }
 private:
  uint8_t pin_; bool stable_=HIGH,raw_=HIGH; uint32_t changed_=0;
};

Button menuButton(BoardPins::BUTTON_MENU);
Button backButton(BoardPins::BUTTON_BACK);
Button dialPressButton(BoardPins::DIAL_PRESS);

String htmlEscape(String value) {
  value.replace("&","&amp;"); value.replace("\"","&quot;");
  value.replace("<","&lt;"); value.replace(">","&gt;"); return value;
}

String cleanDisplay(String value, size_t maximum) {
  value.toUpperCase();
  String clean; clean.reserve(value.length());
  bool previousSpace=false;
  for (size_t i=0;i<value.length();++i) {
    char c=value[i];
    if (c < 32 || c > 126) c=' ';
    if (c==' ' && previousSpace) continue;
    clean += c; previousSpace=(c==' ');
  }
  clean.trim();
  if (clean.length()>maximum) clean=clean.substring(0,maximum);
  return clean;
}

String localClock() {
  struct tm info;
  if (getLocalTime(&info,10)) {
    char output[9]; strftime(output,sizeof(output),"%I:%M %p",&info);
    String value(output); if (value[0]=='0') value.remove(0,1); return value;
  }
  return "--:--";
}

String connectionState() {
  if (offlineDemo) return "OFFLINE";
  return WiFi.status()==WL_CONNECTED ? "ONLINE" : "OFFLINE";
}

void loadOfflineDemo() {
  arrivals=ArrivalSnapshot{}; arrivals.valid=true;
  arrivals.north[0]=3; arrivals.north[1]=8; arrivals.north[2]=14;
  arrivals.south[0]=5; arrivals.south[1]=11; arrivals.south[2]=17;
  weather.valid=true; weather.temperature=72; weather.wind=6; weather.humidity=52;
  weather.code=1; weather.condition="MOSTLY CLEAR";
  serviceAlert=""; mtaError="OFFLINE SAMPLE ARRIVALS"; weatherError="";
}

void loadSettings() {
  preferences.begin("trainmini",true);
  configured=preferences.getBool("configured",false);
  wifiSsid=preferences.getString("ssid","");
  wifiPassword=preferences.getString("pass","");
  selectedRouteId=preferences.getString("route","");
  selectedStationId=preferences.getString("station","");
  const bool modeSet=preferences.getBool("modeset",false);
  const bool savedDemo=preferences.getBool("demo",false);
  preferences.end();
  if (wifiSsid.isEmpty() && UserConfig::WIFI_SSID[0]) {
    wifiSsid=UserConfig::WIFI_SSID; wifiPassword=UserConfig::WIFI_PASSWORD;
  }
  offlineDemo=modeSet ? savedDemo : UserConfig::START_IN_OFFLINE_DEMO;
  selectedRoute=SubwayCatalog::findRoute(selectedRouteId);
  selectedStation=selectedRoute ? SubwayCatalog::findStation(*selectedRoute,selectedStationId) : nullptr;
  if (!selectedRoute || !selectedStation) configured=false;
}

void drawBadge(int centerX, int centerY, const String &badge) {
  display.fillCircle(centerX,centerY,10,true);
  const uint8_t scale=badge.length()==1 ? 2 : 1;
  const int x=display.centeredTextX(centerX,badge,scale);
  display.text(x,centerY-(7*scale)/2,badge,scale,false);
}

String minuteText(int minute) {
  if (minute < 0) return "--";
  if (minute == 0) return "DUE";
  return String(minute);
}

void renderDirectionCard(int x, const String &label, const int values[3]) {
  display.rect(x,27,119,55);
  display.text(x+5,31,cleanDisplay(label,17),1);
  display.line(x+4,41,x+114,41);
  const String first=minuteText(values[0]);
  const uint8_t firstScale=first=="DUE" ? 2 : 3;
  display.text(x+6,47,first,firstScale);
  if (first != "DUE") display.text(x+6+display.textWidth(first,firstScale)+3,58,"MIN",1);
  display.text(x+72,47,"NEXT",1);
  display.text(x+72,61,minuteText(values[1])+" / "+minuteText(values[2]),1);
}

void renderSetupScreen() {
  display.clear();
  display.text(5,5,"TRAIN UI MINI",2);
  display.line(5,23,244,23);
  display.text(5,31,"CHOOSE TRAIN + STATION",1);
  display.text(5,47,"WI-FI: TRAINUIMINI",1);
  display.text(5,61,"PASSWORD: TRAINUI1",1);
  display.text(5,75,"OPEN: 192.168.4.1",1);
  display.text(5,94,"SETUP CLOSES IN 15 MIN",1);
  display.text(5,112,"MENU REOPENS SETUP",1);
  display.show(false);
}

void renderDashboard() {
  if (!selectedRoute || !selectedStation) { renderSetupScreen(); return; }
  display.clear();
  drawBadge(14,12,selectedRoute->badge);
  display.text(30,3,cleanDisplay(selectedStation->name,27),1);
  const String state=connectionState();
  display.text(246-display.textWidth(state,1),3,state,1);
  display.text(30,14,cleanDisplay(String(selectedStation->borough)+" / "+selectedRoute->service,24),1);
  const String clock=localClock();
  display.text(246-display.textWidth(clock,1),14,clock,1);
  display.line(4,24,246,24);

  renderDirectionCard(4,selectedStation->northLabel,arrivals.north);
  renderDirectionCard(127,selectedStation->southLabel,arrivals.south);

  display.rect(4,86,242,35);
  const String statusTitle = serviceAlert.isEmpty() ? "GOOD SERVICE" : "SERVICE ALERT";
  display.text(9,90,statusTitle,1);
  String weatherLine=weather.valid ? "TEMP "+String(weather.temperature)+"F" :
                     (weatherError.isEmpty() ? "TEMP --" : "TEMP ERR");
  weatherLine=cleanDisplay(weatherLine,19);
  display.text(241-display.textWidth(weatherLine,1),90,weatherLine,1);
  String statusLine;
  if (!serviceAlert.isEmpty()) statusLine=serviceAlert;
  else if (offlineDemo) statusLine="OFFLINE DEMO / PRESS DIAL FOR LIVE";
  else if (!mtaError.isEmpty()) statusLine=mtaError;
  else statusLine=String(selectedRoute->service)+" IS OPERATING NORMALLY";
  display.text(9,101,cleanDisplay(statusLine,38),1);
  String footer="UPDATED "+localClock()+" / "+state;
  display.text(9,112,cleanDisplay(footer,30),1);
  display.text(241-display.textWidth("ALOE",1),112,"ALOE",1);

  const bool fast=hasShownDashboard && (++screenRefreshCount % 10 != 0);
  display.show(fast); hasShownDashboard=true;
}

String pageStart() {
  return F("<!doctype html><html><head><meta name=viewport content='width=device-width,initial-scale=1'>"
           "<title>Train UI Mini</title><style>body{font:17px system-ui;max-width:650px;margin:28px auto;padding:0 18px;background:#071321;color:#f5f8ff}"
           "h1{font-size:31px;margin-bottom:6px}.muted{color:#9cb0cf}label{display:block;font-weight:700;margin-top:18px}"
           "input,select{box-sizing:border-box;width:100%;font:inherit;padding:12px;border:2px solid #526b91;border-radius:8px;background:#fff;color:#111}"
           ".check{display:flex;gap:10px;align-items:center}.check input{width:auto}button{width:100%;margin-top:24px;background:#fff;color:#071321;border:0;border-radius:8px;padding:14px;font:800 18px system-ui}</style></head><body>");
}

String routeSetupPage() {
  String page=pageStart(); page.reserve(9000);
  page += F("<h1>Train UI Mini</h1><p class=muted>Connect Wi-Fi, choose an NYC train, then choose a station served by it.</p>"
            "<form method=post action=/stations><label>Home Wi-Fi name</label><input name=ssid required value=\"");
  page += htmlEscape(wifiSsid);
  page += F("\"><label>Wi-Fi password</label><input type=password name=pass placeholder='Leave blank to keep saved password'>"
            "<label>Train</label><select name=route required><option value=''>Choose a train...</option>");
  for (size_t i=0;i<SubwayCatalog::ROUTE_COUNT;++i) {
    const auto &route=SubwayCatalog::ROUTES[i];
    page += "<option value='"+String(route.id)+"'";
    if (selectedRouteId==route.id) page += " selected";
    page += ">"+htmlEscape(String(route.service))+"</option>";
  }
  page += F("</select><label class=check><input type=checkbox name=demo value=1>Start with offline sample arrivals</label>"
            "<button type=submit>Next: choose station</button></form></body></html>");
  return page;
}

String stationSetupPage(const SubwayCatalog::RouteDef &route) {
  String page=pageStart(); page.reserve(14000);
  page += "<h1>Choose a station</h1><p class=muted>Showing stations served by the "+htmlEscape(String(route.service))+".</p>";
  page += "<form method=post action=/save><input type=hidden name=ssid value=\""+htmlEscape(server.arg("ssid"))+"\">";
  page += "<input type=hidden name=pass value=\""+htmlEscape(server.arg("pass"))+"\">";
  page += "<input type=hidden name=route value=\""+String(route.id)+"\">";
  if (server.hasArg("demo")) page += "<input type=hidden name=demo value=1>";
  page += "<label>Station</label><select name=station required><option value=''>Choose a station...</option>";
  for (uint16_t i=0;i<route.stationCount;++i) {
    const auto &station=SubwayCatalog::STATIONS[route.stationStart+i];
    page += "<option value='"+String(station.id)+"'";
    if (selectedRouteId==route.id && selectedStationId==station.id) page += " selected";
    page += ">"+htmlEscape(String(station.name))+" ("+station.borough+")</option>";
  }
  page += F("</select><button type=submit>Save and start display</button></form>"
            "<form method=get action='/'><button type=submit>Back</button></form></body></html>");
  return page;
}

void stopPortal() {
  if (!portalRunning) return;
  server.stop(); WiFi.softAPdisconnect(true); portalRunning=false;
  if (WiFi.status()==WL_CONNECTED) WiFi.mode(WIFI_STA);
}

void startPortal() {
  WiFi.mode(WIFI_AP_STA); WiFi.softAP(SETUP_SSID,SETUP_PASSWORD);
  server.on("/",HTTP_GET,[]{ server.send(200,"text/html",routeSetupPage()); });
  server.on("/stations",HTTP_POST,[]{
    const auto *route=SubwayCatalog::findRoute(server.arg("route"));
    if (!route) { server.send(400,"text/plain","Choose a valid train, then go back."); return; }
    server.send(200,"text/html",stationSetupPage(*route));
  });
  server.on("/save",HTTP_POST,[]{
    const auto *route=SubwayCatalog::findRoute(server.arg("route"));
    const auto *station=route ? SubwayCatalog::findStation(*route,server.arg("station")) : nullptr;
    const String newSsid=server.arg("ssid");
    if (!route || !station || (newSsid.isEmpty() && UserConfig::WIFI_SSID[0]=='\0')) {
      server.send(400,"text/plain","Wi-Fi, train, or station is invalid. Go back and try again."); return;
    }
    preferences.begin("trainmini",false);
    preferences.putBool("configured",true); preferences.putString("ssid",newSsid);
    if (!server.arg("pass").isEmpty()) preferences.putString("pass",server.arg("pass"));
    preferences.putString("route",route->id); preferences.putString("station",station->id);
    preferences.putBool("demo",server.hasArg("demo")); preferences.putBool("modeset",true);
    preferences.end();
    server.send(200,"text/html","<h2>Saved.</h2><p>Train UI Mini is restarting.</p>");
    delay(900); ESP.restart();
  });
  server.onNotFound([]{server.sendHeader("Location","/",true); server.send(302,"text/plain","");});
  server.begin(); portalRunning=true; portalStarted=millis(); renderSetupScreen();
}

bool connectWifi() {
  if (wifiSsid.isEmpty()) return false;
  WiFi.mode(WIFI_STA); WiFi.begin(wifiSsid.c_str(),wifiPassword.c_str());
  const uint32_t started=millis();
  while (WiFi.status()!=WL_CONNECTED && millis()-started<18000) delay(150);
  if (WiFi.status()==WL_CONNECTED) {
    configTzTime("EST5EDT,M3.2.0/2,M11.1.0/2","pool.ntp.org","time.nist.gov"); return true;
  }
  return false;
}

void updateLive(bool forceAll=false) {
  if (offlineDemo) { loadOfflineDemo(); renderDashboard(); return; }
  if (WiFi.status()!=WL_CONNECTED && !connectWifi()) {
    mtaError="WI-FI UNAVAILABLE"; loadOfflineDemo(); offlineDemo=true; renderDashboard(); return;
  }
  const uint32_t now=millis();
  if (forceAll || now-lastArrivalFetch>=ARRIVAL_REFRESH_MS) {
    ArrivalSnapshot fresh;
    if (mta.fetchArrivals(selectedRoute->feedUrl,selectedRoute->aliases,
                          selectedStation->northStop,selectedStation->southStop,fresh)) arrivals=fresh;
    else mtaError=fresh.error;
    if (fresh.valid) mtaError="";
    lastArrivalFetch=now;
  }
  const uint32_t weatherInterval=(weather.valid && weatherError.isEmpty()) ?
                                 WEATHER_REFRESH_MS : ARRIVAL_REFRESH_MS;
  if (forceAll || now-lastWeatherFetch>=weatherInterval) {
    MiniWeatherSnapshot fresh;
    if (weatherClient.fetch(fresh,weatherError)) weather=fresh;
    lastWeatherFetch=now;
  }
  if (forceAll || now-lastAlertFetch>=ALERT_REFRESH_MS) {
    String freshAlert,error;
    if (mta.fetchAlert(selectedRoute->aliases,selectedStation->id,
                       selectedStation->northStop,selectedStation->southStop,freshAlert,error)) serviceAlert=freshAlert;
    lastAlertFetch=now;
  }
  renderDashboard();
}
}  // namespace

void setup() {
  Serial.begin(115200);
  pinMode(BoardPins::POWER_LED,OUTPUT); digitalWrite(BoardPins::POWER_LED,HIGH);
  display.begin(); menuButton.begin(); backButton.begin(); dialPressButton.begin();
  loadSettings();
  if (!configured) startPortal();
  else if (offlineDemo) { loadOfflineDemo(); renderDashboard(); }
  else updateLive(true);
}

void loop() {
  if (portalRunning) {
    server.handleClient();
    if (millis()-portalStarted>=PORTAL_TIMEOUT_MS) { stopPortal(); renderDashboard(); }
  } else {
    if (menuButton.pressed()) startPortal();
    if (dialPressButton.pressed()) {
      offlineDemo=!offlineDemo;
      preferences.begin("trainmini",false); preferences.putBool("demo",offlineDemo);
      preferences.putBool("modeset",true); preferences.end();
      if (offlineDemo) { loadOfflineDemo(); renderDashboard(); }
      else updateLive(true);
    }
    if (backButton.pressed() && !offlineDemo) updateLive(true);
    if (!offlineDemo && millis()-lastArrivalFetch>=ARRIVAL_REFRESH_MS) updateLive(false);
  }
  delay(5);
}

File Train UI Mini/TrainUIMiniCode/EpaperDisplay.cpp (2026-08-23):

#include "EpaperDisplay.h"

#include <SPI.h>

#include "BoardPins.h"

namespace {
SPIClass &epdSpi = SPI;
constexpr uint8_t SPACE[5] = {0,0,0,0,0};
constexpr uint8_t UNKNOWN[5] = {0x02,0x01,0x51,0x09,0x06};
constexpr uint8_t GLYPHS[][5] = {
  {0x3E,0x51,0x49,0x45,0x3E},{0x00,0x42,0x7F,0x40,0x00},
  {0x42,0x61,0x51,0x49,0x46},{0x21,0x41,0x45,0x4B,0x31},
  {0x18,0x14,0x12,0x7F,0x10},{0x27,0x45,0x45,0x45,0x39},
  {0x3C,0x4A,0x49,0x49,0x30},{0x01,0x71,0x09,0x05,0x03},
  {0x36,0x49,0x49,0x49,0x36},{0x06,0x49,0x49,0x29,0x1E},
  {0x7E,0x11,0x11,0x11,0x7E},{0x7F,0x49,0x49,0x49,0x36},
  {0x3E,0x41,0x41,0x41,0x22},{0x7F,0x41,0x41,0x22,0x1C},
  {0x7F,0x49,0x49,0x49,0x41},{0x7F,0x09,0x09,0x09,0x01},
  {0x3E,0x41,0x49,0x49,0x7A},{0x7F,0x08,0x08,0x08,0x7F},
  {0x00,0x41,0x7F,0x41,0x00},{0x20,0x40,0x41,0x3F,0x01},
  {0x7F,0x08,0x14,0x22,0x41},{0x7F,0x40,0x40,0x40,0x40},
  {0x7F,0x02,0x0C,0x02,0x7F},{0x7F,0x04,0x08,0x10,0x7F},
  {0x3E,0x41,0x41,0x41,0x3E},{0x7F,0x09,0x09,0x09,0x06},
  {0x3E,0x41,0x51,0x21,0x5E},{0x7F,0x09,0x19,0x29,0x46},
  {0x46,0x49,0x49,0x49,0x31},{0x01,0x01,0x7F,0x01,0x01},
  {0x3F,0x40,0x40,0x40,0x3F},{0x1F,0x20,0x40,0x20,0x1F},
  {0x3F,0x40,0x38,0x40,0x3F},{0x63,0x14,0x08,0x14,0x63},
  {0x07,0x08,0x70,0x08,0x07},{0x61,0x51,0x49,0x45,0x43}
};
constexpr uint8_t DASH[5] = {0x08,0x08,0x08,0x08,0x08};
constexpr uint8_t DOT[5] = {0,0x60,0x60,0,0};
constexpr uint8_t COLON[5] = {0,0x36,0x36,0,0};
constexpr uint8_t SLASH[5] = {0x20,0x10,0x08,0x04,0x02};
constexpr uint8_t EXCLAMATION[5] = {0,0,0x5F,0,0};
constexpr uint8_t PLUS[5] = {0x08,0x08,0x3E,0x08,0x08};
constexpr uint8_t PERCENT[5] = {0x63,0x13,0x08,0x64,0x63};
}

void EpaperDisplay::begin() {
  pinMode(BoardPins::EPD_POWER, OUTPUT);
  pinMode(BoardPins::EPD_RESET, OUTPUT);
  pinMode(BoardPins::EPD_DC, OUTPUT);
  pinMode(BoardPins::EPD_CS, OUTPUT);
  pinMode(BoardPins::EPD_BUSY, INPUT);
  digitalWrite(BoardPins::EPD_POWER, HIGH);
  digitalWrite(BoardPins::EPD_CS, HIGH);
  epdSpi.begin(BoardPins::EPD_SCK, -1, BoardPins::EPD_MOSI, BoardPins::EPD_CS);
  clear();
}

void EpaperDisplay::command(uint8_t value) {
  epdSpi.beginTransaction(SPISettings(4000000, MSBFIRST, SPI_MODE0));
  digitalWrite(BoardPins::EPD_DC, LOW); digitalWrite(BoardPins::EPD_CS, LOW);
  epdSpi.transfer(value);
  digitalWrite(BoardPins::EPD_CS, HIGH); epdSpi.endTransaction();
}

void EpaperDisplay::data(uint8_t value) {
  epdSpi.beginTransaction(SPISettings(4000000, MSBFIRST, SPI_MODE0));
  digitalWrite(BoardPins::EPD_DC, HIGH); digitalWrite(BoardPins::EPD_CS, LOW);
  epdSpi.transfer(value);
  digitalWrite(BoardPins::EPD_CS, HIGH); epdSpi.endTransaction();
}

void EpaperDisplay::reset() {
  delay(100); digitalWrite(BoardPins::EPD_RESET, HIGH); delay(10);
  digitalWrite(BoardPins::EPD_RESET, LOW); delay(10);
  digitalWrite(BoardPins::EPD_RESET, HIGH); delay(10);
}

bool EpaperDisplay::waitUntilReady(uint32_t timeoutMs) {
  const uint32_t started = millis();
  while (digitalRead(BoardPins::EPD_BUSY) == HIGH) {
    if (millis() - started >= timeoutMs) return false;
    delay(1);
  }
  return true;
}

void EpaperDisplay::configureRam() {
  // A controller reset also resets its scan direction and RAM window. Apply
  // this after every reset so full and fast refreshes cannot change rotation.
  command(0x01); data(0xF9); data(0x00); data(0x00);
  command(0x11); data(0x03);
  command(0x44); data(0x00); data(0x0F);
  command(0x45); data(0x00); data(0x00); data(0xF9); data(0x00);
  command(0x4E); data(0x00);
  command(0x4F); data(0x00); data(0x00);
}

bool EpaperDisplay::initializeFull() {
  digitalWrite(BoardPins::EPD_POWER, HIGH); delay(100); reset();
  if (!waitUntilReady()) return false;
  command(0x12); if (!waitUntilReady()) return false;
  configureRam();
  command(0x3C); data(0x01);
  command(0x18); data(0x80);
  return waitUntilReady();
}

bool EpaperDisplay::initializeFast() {
  digitalWrite(BoardPins::EPD_POWER, HIGH); delay(20);
  digitalWrite(BoardPins::EPD_RESET, LOW); delay(10);
  digitalWrite(BoardPins::EPD_RESET, HIGH); delay(10);
  command(0x12); if (!waitUntilReady()) return false;
  command(0x18); data(0x80);
  command(0x22); data(0xB1); command(0x20); if (!waitUntilReady()) return false;
  command(0x1A); data(0x64); data(0x00);
  command(0x22); data(0x91); command(0x20);
  if (!waitUntilReady()) return false;
  configureRam();
  return waitUntilReady();
}

void EpaperDisplay::clear(bool black) { memset(buffer_, black ? 0xFF : 0x00, sizeof(buffer_)); }

void EpaperDisplay::pixel(int x, int y, bool black) {
  if (x < 0 || x >= WIDTH || y < 0 || y >= HEIGHT) return;
  // Fixed landscape orientation with the CrowPanel USB-C connector above the
  // screen. Keep rotation here so every UI and refresh path uses it.
  const int rawX = HEIGHT - y - 1, rawY = x;
  const size_t address = rawX / 8 + rawY * (RAW_HEIGHT / 8);
  const uint8_t mask = 0x80 >> (rawX % 8);
  if (black) buffer_[address] |= mask; else buffer_[address] &= ~mask;
}

void EpaperDisplay::line(int x0, int y0, int x1, int y1, bool black) {
  const int dx = abs(x1-x0), sx = x0 < x1 ? 1 : -1;
  const int dy = -abs(y1-y0), sy = y0 < y1 ? 1 : -1;
  int error = dx + dy;
  while (true) {
    pixel(x0,y0,black); if (x0 == x1 && y0 == y1) break;
    const int twice = 2*error;
    if (twice >= dy) { error += dy; x0 += sx; }
    if (twice <= dx) { error += dx; y0 += sy; }
  }
}

void EpaperDisplay::rect(int x, int y, int width, int height, bool black) {
  line(x,y,x+width-1,y,black); line(x,y,x,y+height-1,black);
  line(x+width-1,y,x+width-1,y+height-1,black);
  line(x,y+height-1,x+width-1,y+height-1,black);
}

void EpaperDisplay::fillRect(int x, int y, int width, int height, bool black) {
  for (int row=y; row<y+height; ++row) line(x,row,x+width-1,row,black);
}

void EpaperDisplay::circle(int cx, int cy, int r, bool black) {
  int x=r, y=0, error=0;
  while (x >= y) {
    pixel(cx+x,cy+y,black); pixel(cx+y,cy+x,black); pixel(cx-y,cy+x,black); pixel(cx-x,cy+y,black);
    pixel(cx-x,cy-y,black); pixel(cx-y,cy-x,black); pixel(cx+y,cy-x,black); pixel(cx+x,cy-y,black);
    if (error <= 0) { ++y; error += 2*y+1; }
    if (error > 0) { --x; error -= 2*x+1; }
  }
}

void EpaperDisplay::fillCircle(int cx, int cy, int r, bool black) {
  for (int y=-r; y<=r; ++y) {
    const int half = static_cast<int>(sqrt(static_cast<float>(r*r-y*y)));
    line(cx-half,cy+y,cx+half,cy+y,black);
  }
}

const uint8_t *EpaperDisplay::glyph(char c) const {
  if (c >= 'a' && c <= 'z') c -= 32;
  if (c >= '0' && c <= '9') return GLYPHS[c-'0'];
  if (c >= 'A' && c <= 'Z') return GLYPHS[10+c-'A'];
  switch (c) {
    case ' ': return SPACE; case '-': return DASH; case '.': return DOT;
    case ':': return COLON; case '/': return SLASH; case '!': return EXCLAMATION;
    case '+': return PLUS; case '%': return PERCENT; default: return UNKNOWN;
  }
}
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

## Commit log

2026-07-27 Refactor D-train departure board layout and functionality
    Refactor and enhance the D-train departure board for better readability and functionality. Adjusted layout, improved color handling, and added system stats display.
2026-07-27 Fix newline at end of file in timertest.py
2026-08-22 Fix Train UI Mini display orientation
    [EpaperDisplay.cpp]
2026-08-22 Show temperature on Train UI Mini
2026-08-23 Fix Mini temperature updates and center route badge
    [TrainUIMiniMain.cpp]
2026-08-29 added BOM and updated freezing
2026-08-31 updt readme and assembly
2026-08-31 updt cad files
    [Only 3DP files.step, case for screen.f3z, case for screen.step]
2026-09-05 added timertest

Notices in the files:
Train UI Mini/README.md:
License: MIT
